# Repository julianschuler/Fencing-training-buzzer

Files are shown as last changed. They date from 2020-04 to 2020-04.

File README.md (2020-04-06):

# Fencing training buzzer
## Overview
This repository contains the schematic and PCB files for training buzzer circuits for sport fencing. These devices are intended to be attached directly to the plug of a foil respectively epee and will beep and flash a LED for a short period of time if a hit is detected. The buzzer circuits are powered by 1F 5.5V supercapacitors and thus can be recharged quickly by connecting them to a 5V wall adapter (less than 150 seconds for a full charge). The weapon of choice (foil or epee) can be selected via a solder jumper on the PCB.

## License
This project is licensed under the MIT license, see [`LICENSE.txt`](LICENSE.txt) for further information.

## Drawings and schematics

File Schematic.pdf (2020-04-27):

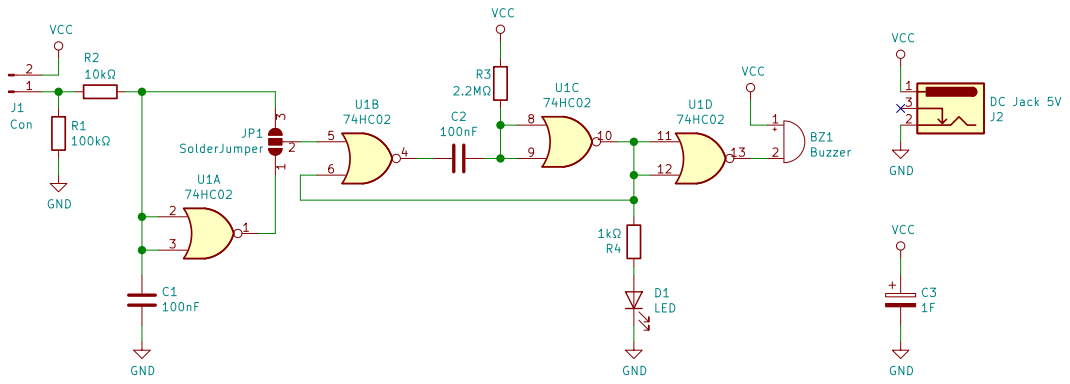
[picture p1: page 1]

File: Fencing-training-buzzer.sch Sheet: /
Id: 1/1 Title:

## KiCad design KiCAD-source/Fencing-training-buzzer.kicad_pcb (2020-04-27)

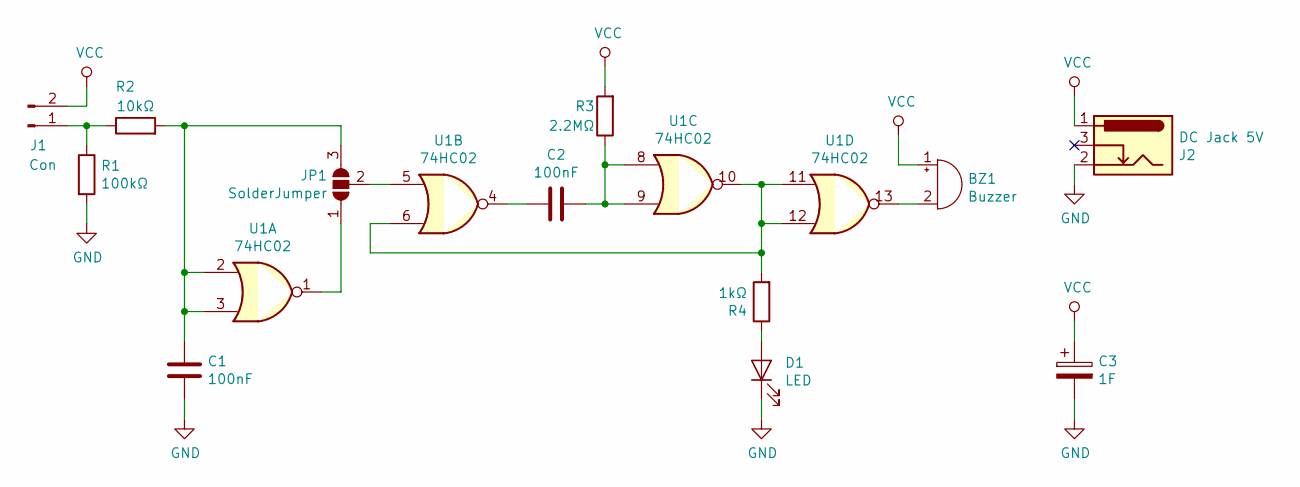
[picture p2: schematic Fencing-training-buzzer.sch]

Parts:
BZ1: Buzzer; Buzzer_12x9.5RM7.6
C1, C2: 100nF; C_Disc_D4.3mm_W1.9mm_P5.00mm
C3: 1F; CP_Radial_Supercap_D21.5mm_P5.00mm
D1: LED; LED_D5.0mm_Horizontal_O1.27mm_Z3.0mm
J1: Con; Foil_Plug_Connector
J2: DC Jack 5V; BarrelJack_Horizontal
JP1: SolderJumper; SolderJumper-3_P1.3mm_Open_RoundedPad1.0x1.5mm
R1: 100kΩ; R_Axial_DIN0207_L6.3mm_D2.5mm_P10.16mm_Horizontal
R2: 10kΩ; R_Axial_DIN0207_L6.3mm_D2.5mm_P10.16mm_Horizontal
R3: 2.2MΩ; R_Axial_DIN0207_L6.3mm_D2.5mm_P10.16mm_Horizontal
R4: 1kΩ; R_Axial_DIN0207_L6.3mm_D2.5mm_P10.16mm_Horizontal
U1: 74HC02; DIP-14_W7.62mm_LongPads

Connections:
GND: C1.1, C3.2, D1.1 (K), J2.2, R1.2, U1.7 (GND)
unnamed: BZ1.2 (+), U1.13
unnamed: C1.2, JP1.3 (B), R2.2, U1.2, U1.3
unnamed: C2.1, R3.1, U1.8, U1.9
unnamed: C2.2, U1.4
unnamed: D1.2 (A), R4.1
unnamed: J1.1, R1.1, R2.1
unnamed: JP1.1 (A), U1.1
unnamed: JP1.2 (C), U1.5
unnamed: R4.2, U1.6, U1.10, U1.11, U1.12
VCC: BZ1.1 (-), C3.1, J1.2, J2.1, R3.2, U1.14 (VCC)

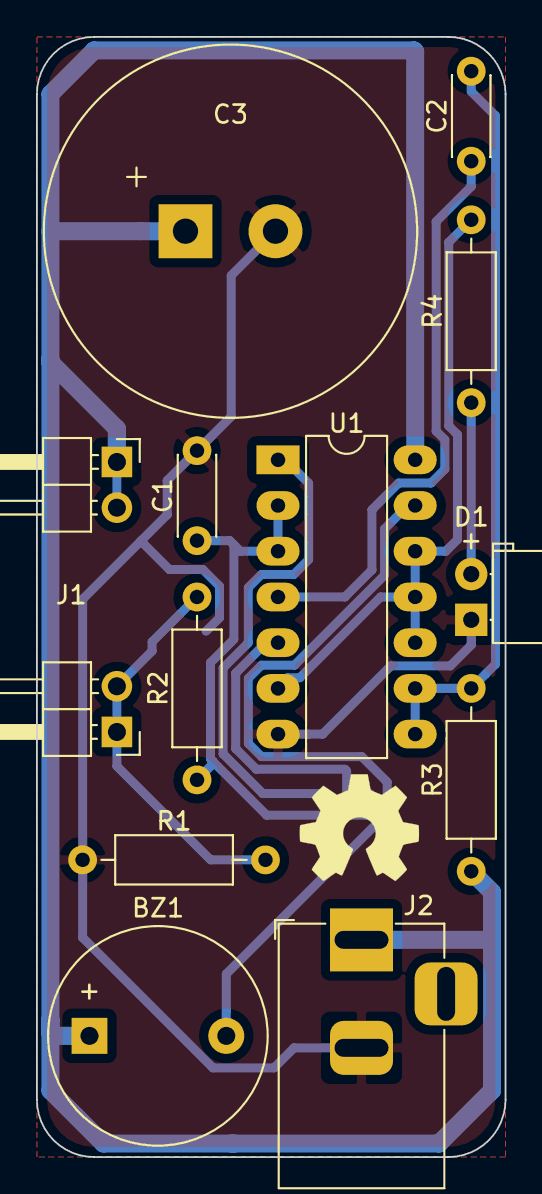
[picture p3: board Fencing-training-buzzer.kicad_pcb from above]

Board: 2 copper layers, 26.0 x 62.2 mm, 13 parts (1 on the bottom side), 11 nets.

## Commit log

2019-12-17 Create PCB for foil training buzzer
    [Training-buzzer-foil.kicad_pcb, Training-buzzer-foil.sch]
2019-12-17 Add gerber files
2019-12-17 Exclude gerber files export directory
2019-12-30 Add schematic for epee training buzzer
    [Training-buzzer-epee.sch]
2019-12-30 Clean up foil training buzzer schematic
    [Training-buzzer-foil.sch]
2019-12-30 Add schematic for configurable training buzzer
    [Training-buzzer-configurable.sch]
2019-12-30 Add schematics as PDF files
2020-04-06 Rework circuit using NOR gates and create PCB
    [Training-buzzer-configurable.kicad_pcb, Training-buzzer-configurable.sch]
2020-04-06 Remove files deprecated due to the circuit rework
    [Training-buzzer-epee.sch, Training-buzzer-foil.kicad_pcb, Training-buzzer-foil.sch]
2020-04-06 Move and rename files for better structure
    [Fencing-training-buzzer.kicad_pcb, Fencing-training-buzzer.sch, Training-buzzer-configurable.sch]
2020-04-27 Fix reverse polarity error at the barrel jack
    [Fencing-training-buzzer.kicad_pcb, Fencing-training-buzzer.sch]
